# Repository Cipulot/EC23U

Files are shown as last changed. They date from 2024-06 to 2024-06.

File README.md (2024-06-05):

# EC23U

Open source numpad Electrostatic Capacitive PCB.

## Introduction

This project is a continuation of my development of open source EC boards.

The supported layout options are the following:

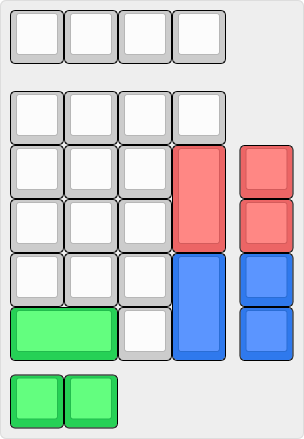
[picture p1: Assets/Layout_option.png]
Layout option


## Technical information

- Layout size: 23U layouts with alternative options
- Compatible switches: EC switches (Topre and NIZ)
- Microcontroller: STM32F401
- Connector: Original OEM JST connector
- Firmware compatibility: QMK (with VIA/VIAL support)
- Protection hardware (present on both the mainboard and both controller versions):
  - Fused
  - ESD protection
- Addressable RGB LED support
- Numlock LED support

## Renders and Prototypes

### Render

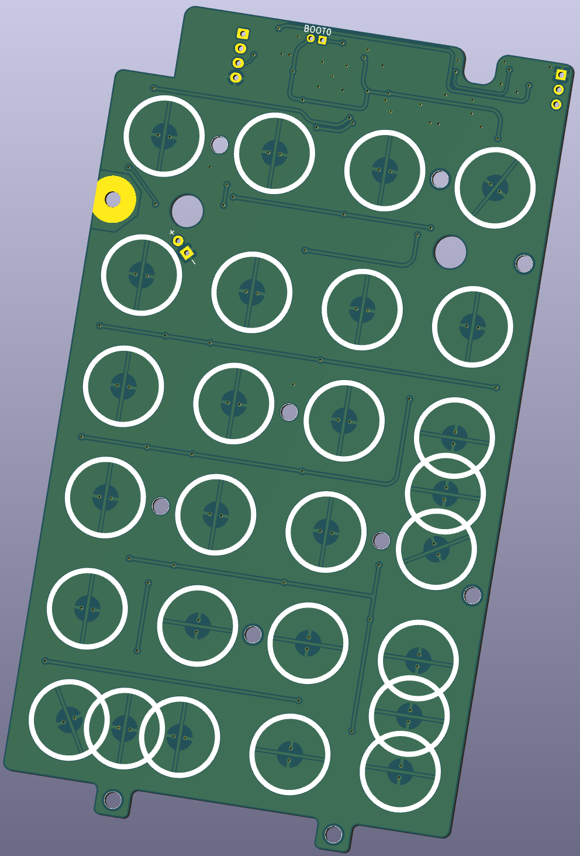
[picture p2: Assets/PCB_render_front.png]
PCB Front Render


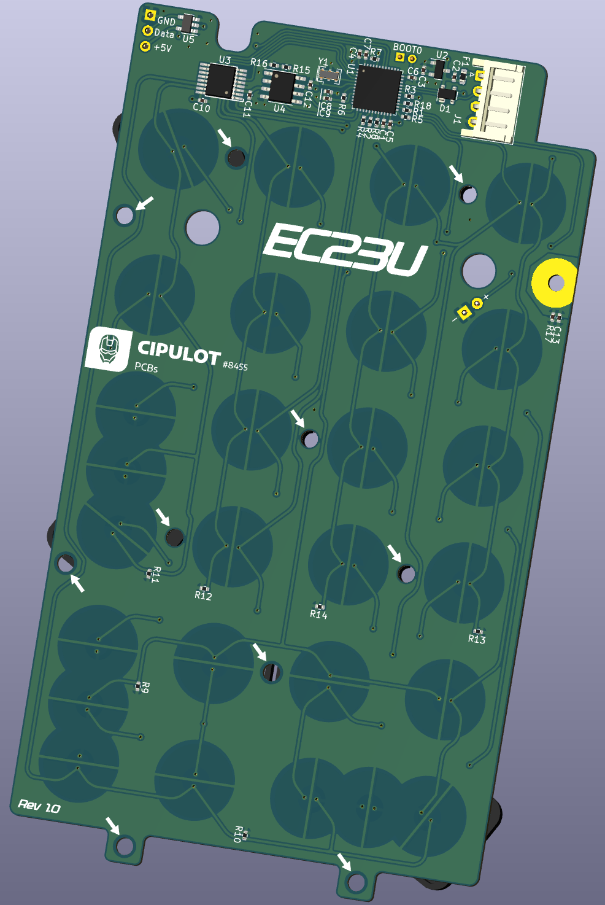
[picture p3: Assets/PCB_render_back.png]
PCB Back Render


### Prototypes

PCB Front

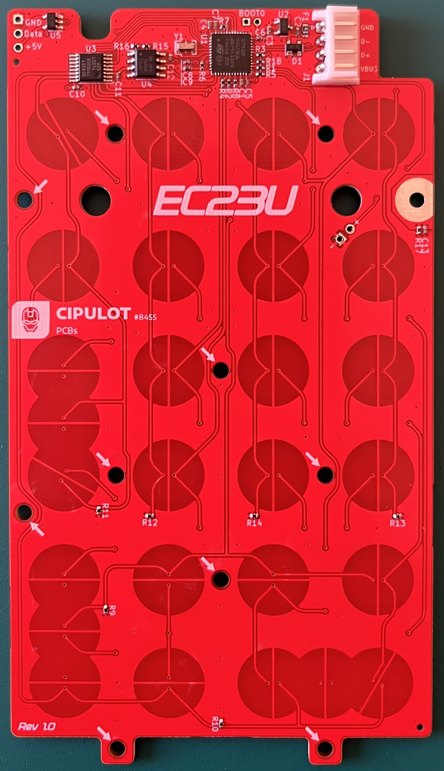
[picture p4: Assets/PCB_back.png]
PCB Back


**NOTE**: The silkscreen text near the JST connector has the `GND` and `VBUS` label swapped. This is wrong and have been fixed in the latest revision.

## Revisions and relative features

### Rev1.0

This revision implements all the main features of the mainboard ad controllers mentioned in the specifications.

#### RGB header

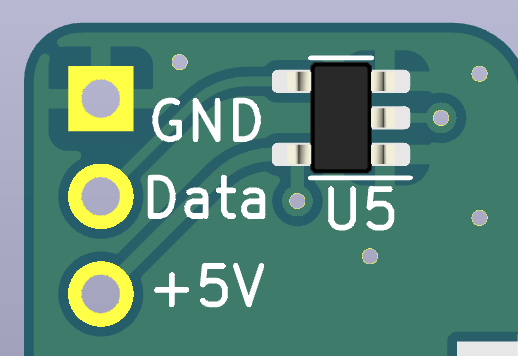
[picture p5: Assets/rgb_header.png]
RGB header


The mainboard features an RGB header for connecting +5V addressable RGB strips. THe properties of the lighting can be controlled through Vial or by assigning RGB control keycodes on the board itself.

#### NumLock Indicator

The mainboard features a NumLock indicator LED. The LED is controlled by the MCU and reacts based on the system state. The LED used is a 3.0mm THT LED. Polarity is signalled by the silkscreen. The indicator is optional.

#### DFU

To access the DFU mode of the mainboard you can perform one of the following actions:

- press the key to which the `QK_BOOT` keycode is assigned (if available)
- while plugging in the board short the `Boot0` pins on the mainboard

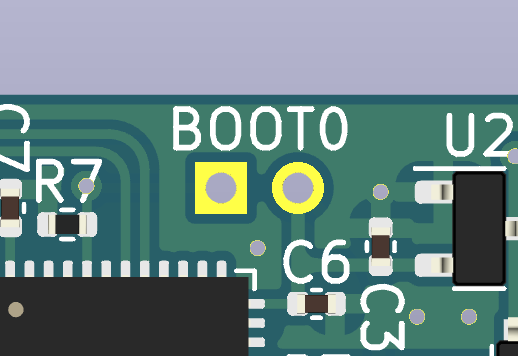
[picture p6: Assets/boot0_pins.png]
Boot0 pins


## PCB order procedure

### Production files

The production can be found in the [Production folder](/Production).

In there you'll find the main PCB files and the JIS and HHKB plates.

As usual the `*.zip` files are the gerber files, `BOM-*.csv` are the BOM (Bill Of Material) files and `POS-*.csv` are the POS/CPL (Footprint POSition/Component Placement List) files.

### Assembly options

Here follows the options to be used for assembly:

- Assembly Side: Bottom
- Confirm Parts Placement: `yes`

## Copyright notice

This project is not endorse nor sponsored in any way by Topre Corporation and PFU Limited. The HHKB Logo and Topre logo are trademarks of their respective owners.

## License

<br />This work is licensed under a <a rel="license" href="http://creativecommons.org/licenses/by-nc-sa/4.0/">Creative Commons Attribution-NonCommercial-ShareAlike 4.0 International License</a>.

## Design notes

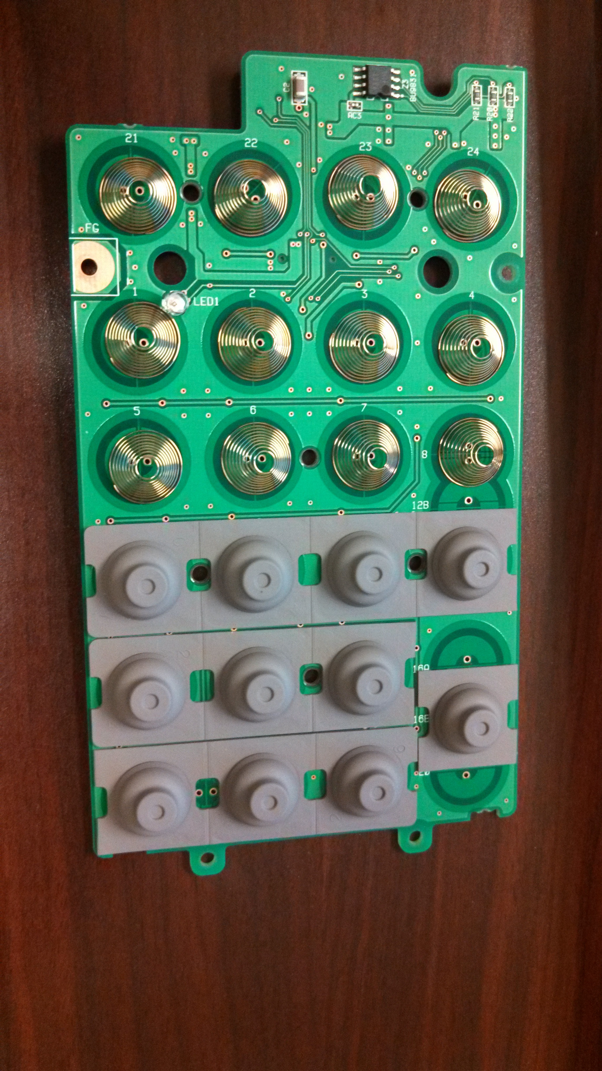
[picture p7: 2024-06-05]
Docs/23U Internals/11 - LMW1pFv.jpg

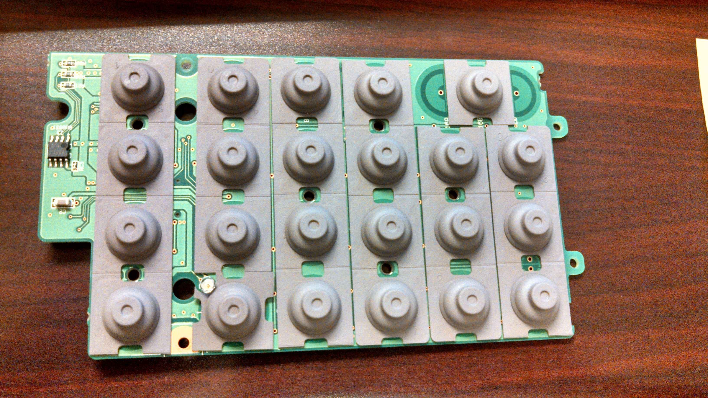
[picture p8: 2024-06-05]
Docs/23U Internals/3 - nLBDdjI.jpg

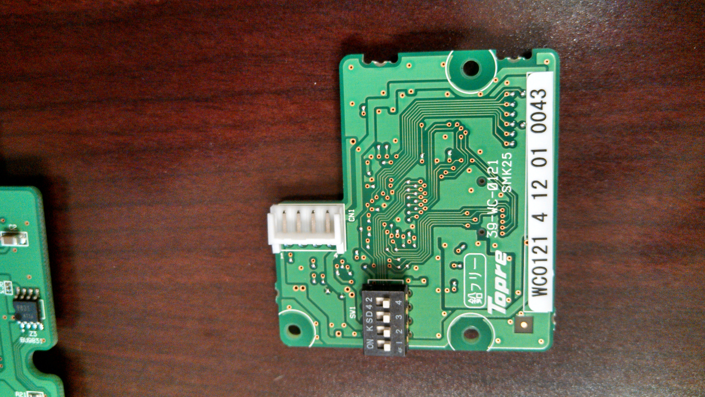
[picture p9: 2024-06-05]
Docs/23U Internals/10 - FUrgEg5.jpg

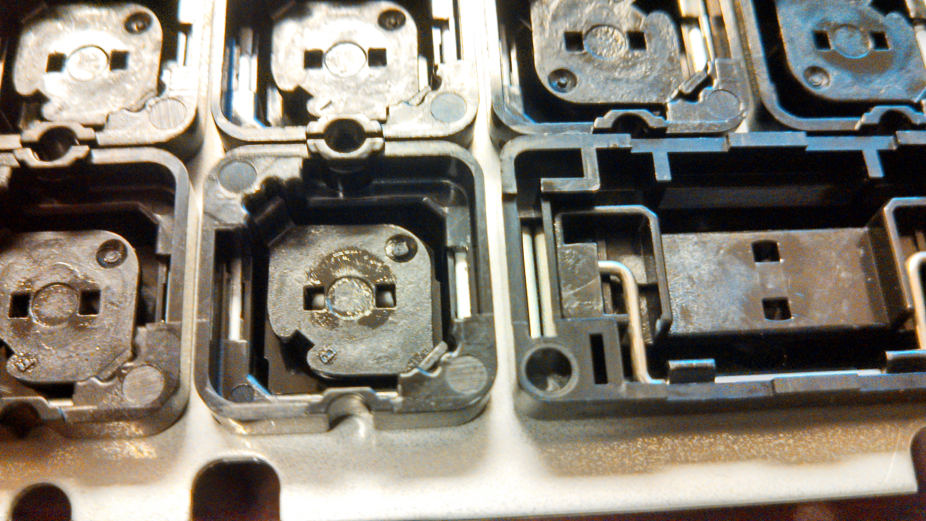
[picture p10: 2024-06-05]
Docs/23U Internals/1 - Ok48gKT.jpg

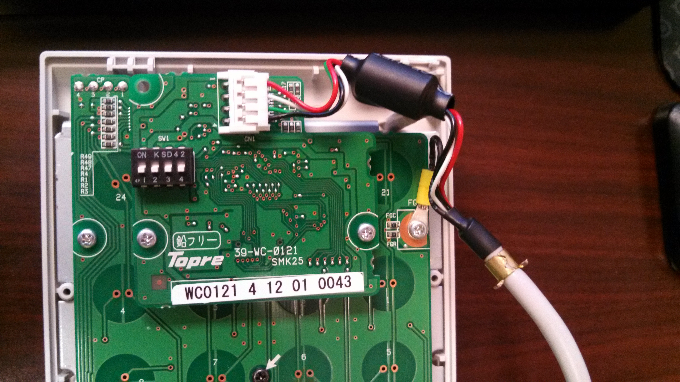
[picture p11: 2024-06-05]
Docs/23U Internals/4 - P8sS34b.jpg

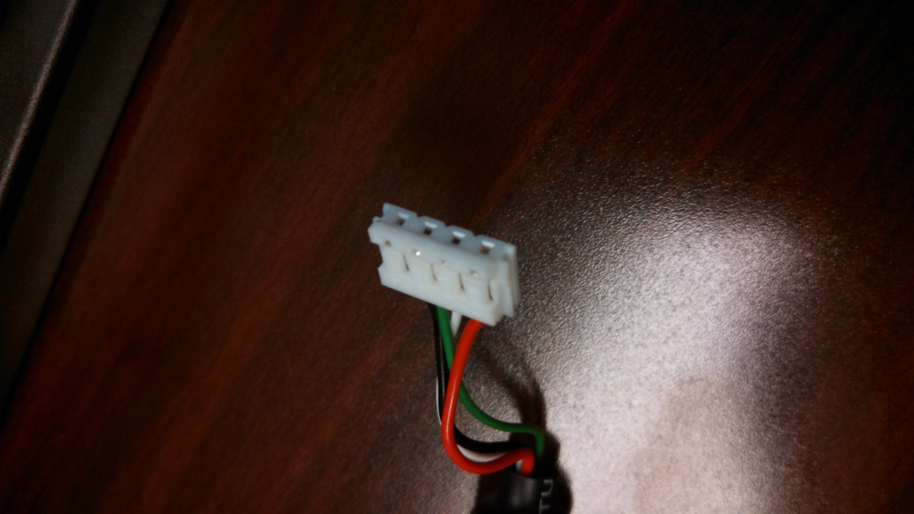
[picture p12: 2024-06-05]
Docs/23U Internals/7 - ExHz7Yd.jpg

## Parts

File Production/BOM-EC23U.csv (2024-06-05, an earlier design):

Comment | Designator | Footprint | LCSC
1k | R16 | R_0402_1005Metric | C11702
STM32F401CBUx | U1 | QFN-48-1EP_7x7mm_P0.5mm_EP5.6x5.6mm | C118825
OPA350 | U4 | SOIC-8_3.9x4.9mm_P1.27mm | C13388
220p | C11 | C_0402_1005Metric | C1530
4.7u | C1 | C_0402_1005Metric | C23733
100 | R1,R18,R2,R4,R5 | R_0402_1005Metric | C25076
330 | R17 | C_0402_1005Metric | C25104
100k | R10,R11,R12,R13,R14,R3,R9 | R_0402_1005Metric | C25741
10k | R6,R7,R8 | R_0402_1005Metric | C25744
47k | R15 | R_0402_1005Metric | C25792
JST | J1 | JST_EH_S4B-EH_1x04_P2.50mm_Horizontal | C265068
PRTR5V0U2X | D1 | SOT-143 | C2827688
100n | C10,C12,C13,C4,C5,C6,C7,C8 | C_0402_1005Metric | C307331
1u | C2,C3,C9 | C_0402_1005Metric | C52923
XC6206PxxxMR | U2 | SOT-23 | C5446
74HC4051 | U3 | TSSOP16 | C5645
500mA | F1 | Fuse_0603_1608Metric | C720073
SN74AHCT1G125 | U5 | SOT-23-5 | C7484
8 MHz | Y1 | Resonator_SMD_Murata_CSTxExxV-3Pin_3.0x1.1mm | C907975

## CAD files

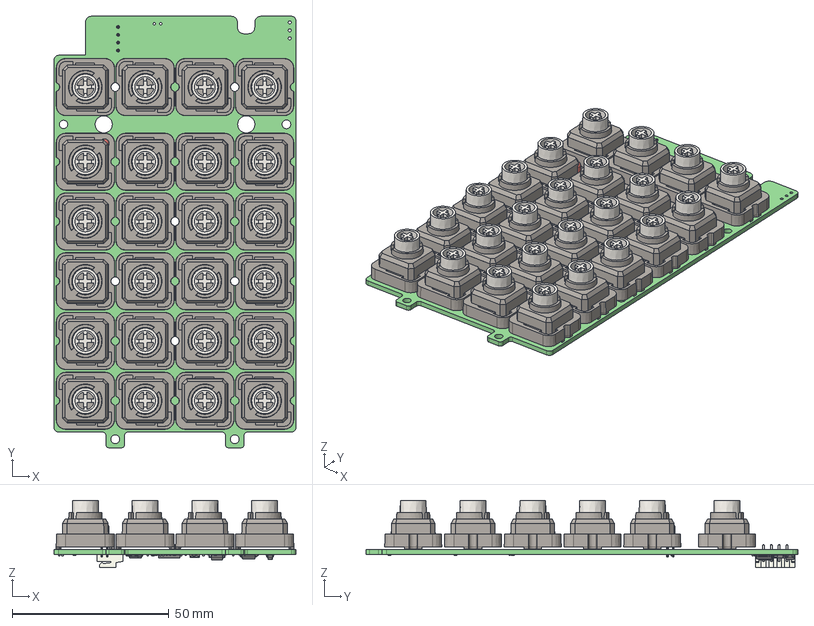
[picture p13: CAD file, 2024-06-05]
Assemblies_3D_Models/EC23U_Full_1U_Numpad.step
77.2 x 137.6 x 21.4 mm
EC23U PCB

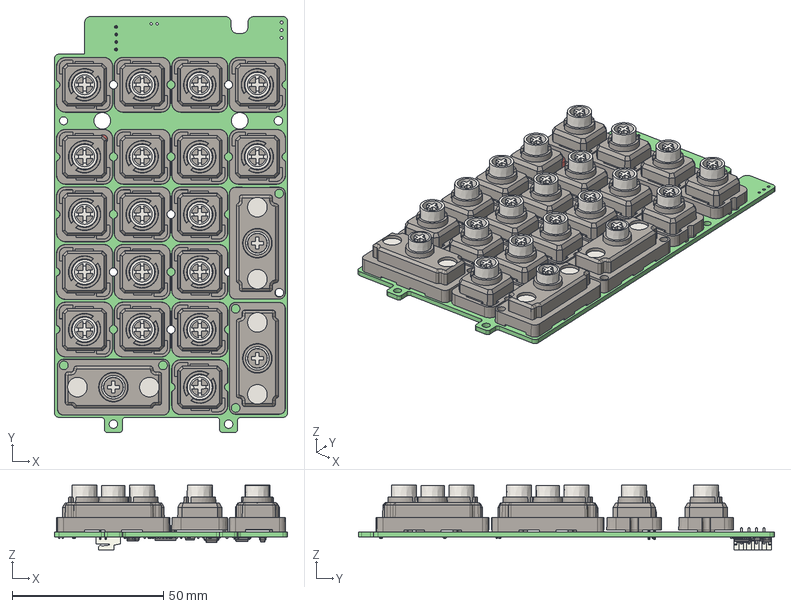
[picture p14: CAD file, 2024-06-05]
Assemblies_3D_Models/EC23U_Standard_Numpad.step
77.2 x 137.6 x 21.4 mm
EC23U PCB

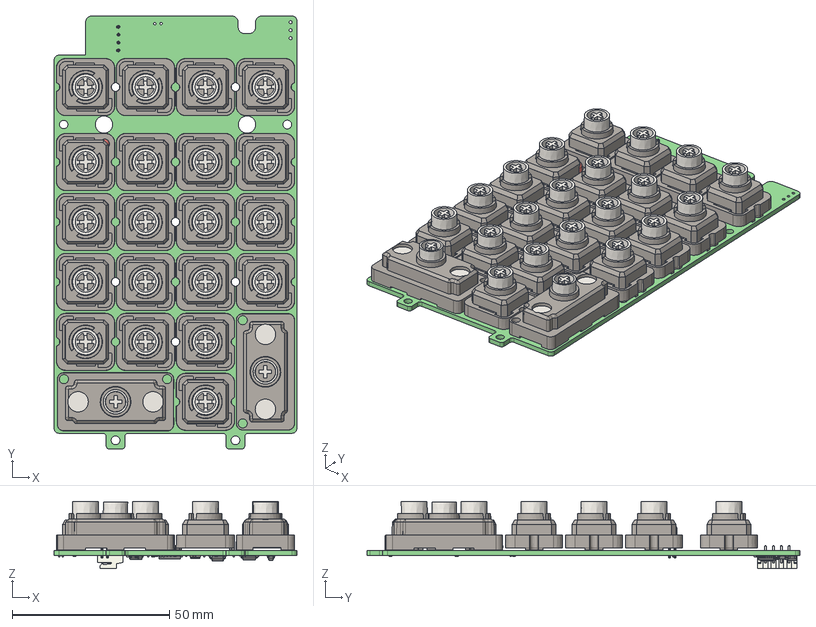
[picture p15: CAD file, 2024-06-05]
Assemblies_3D_Models/EC23U_Apple_Numpad.step
77.2 x 137.6 x 21.4 mm
EC23U PCB

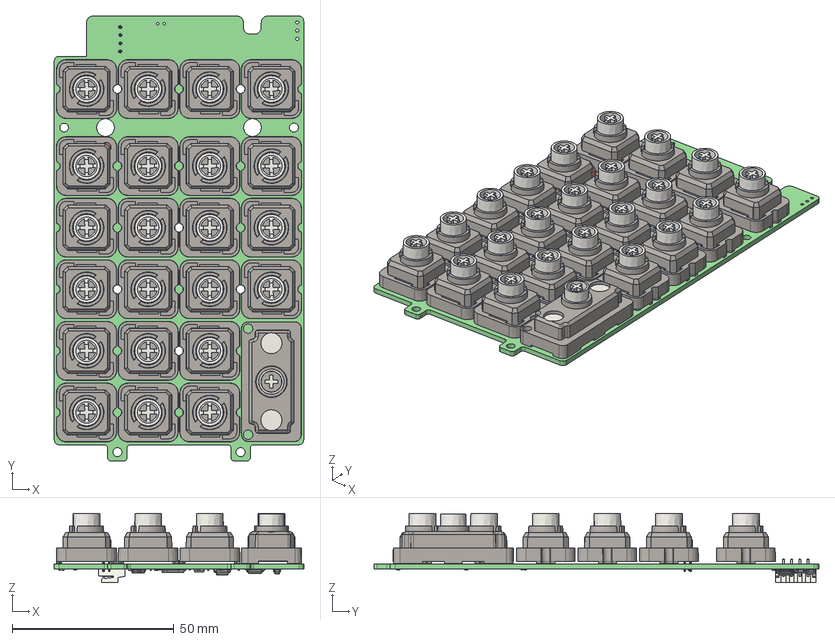
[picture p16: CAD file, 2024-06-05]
Assemblies_3D_Models/EC23U_Realforce_Numpad.step
77.2 x 137.6 x 21.4 mm
EC23U PCB

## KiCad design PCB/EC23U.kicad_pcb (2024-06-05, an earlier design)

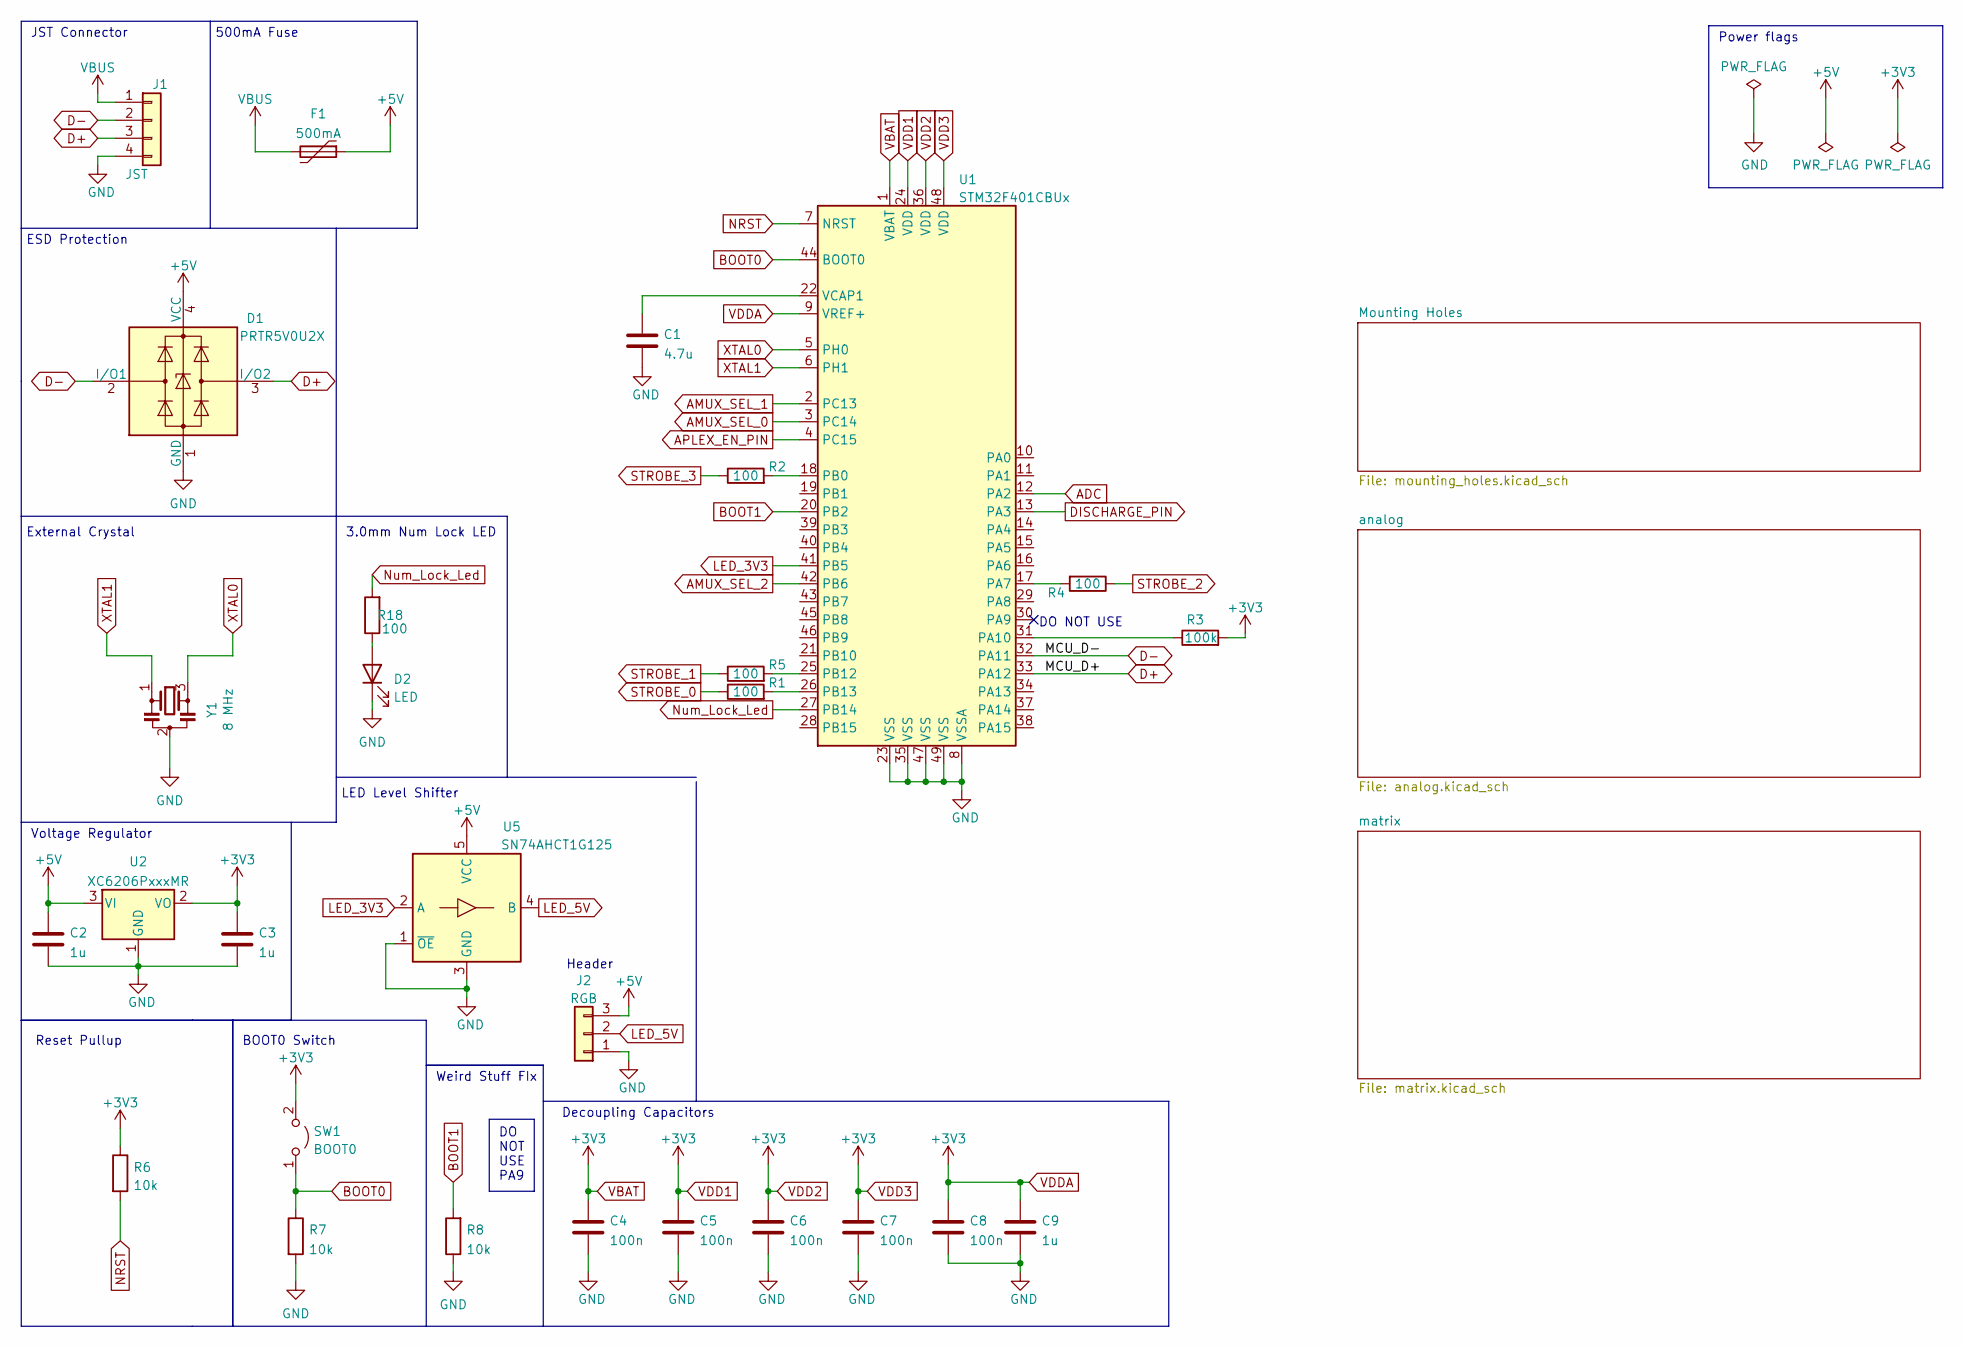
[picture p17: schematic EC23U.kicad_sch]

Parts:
C1: 4.7u; C_0402_1005Metric; LCSC C23733
C2, C3, C9: 1u; C_0402_1005Metric; LCSC C52923
C4, C5, C6, C7, C8: 100n; C_0402_1005Metric; LCSC C307331
D1: PRTR5V0U2X; SOT-143; LCSC C2827688
D2: LED; LED_D3.0mm
F1: 500mA; Fuse_0603_1608Metric; LCSC C720073
J1: JST; JST_EH_S4B-EH_1x04_P2.50mm_Horizontal; LCSC C265068
J2: RGB; PinSocket_1x03_P2.54mm_Vertical
R1, R2, R4, R5, R18: 100; R_0402_1005Metric; LCSC C25076
R3: 100k; R_0402_1005Metric; LCSC C25741
R6, R7, R8: 10k; R_0402_1005Metric; LCSC C25744
SW1: BOOT0; PinHeader_1x02_P2.00mm_Vertical
U1: STM32F401CBUx; QFN-48-1EP_7x7mm_P0.5mm_EP5.6x5.6mm; LCSC C118825
U2: XC6206PxxxMR; SOT-23; LCSC C5446
U5: SN74AHCT1G125; SOT-23-5; LCSC C7484
Y1: 8 MHz; Resonator_SMD_Murata_CSTxExxV-3Pin_3.0x1.1mm; LCSC C907975

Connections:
+5V: C2.1, D1.4 (VCC), F1.1, J2.3, U2.3 (VI), U5.5 (VCC)
ADC: U1.12 (PA2); also elsewhere on the board
AMUX_SEL_0: U1.3 (PC14); also elsewhere on the board
AMUX_SEL_1: U1.2 (PC13); also elsewhere on the board
AMUX_SEL_2: U1.42 (PB6); also elsewhere on the board
APLEX_EN_PIN: U1.4 (PC15); also elsewhere on the board
APLEX_OUT_PIN: U1.13 (PA3); also elsewhere on the board
BOOT0: R7.1, SW1.1 (A), U1.44 (BOOT0)
BOOT1: R8.2, U1.20 (PB2)
D+: D1.3 (I/O2), J1.3, U1.33 (PA12)
D-: D1.2 (I/O1), J1.2, U1.32 (PA11)
GND: C1.2, C2.2, C3.2, C4.2, C5.2, C6.2, C7.2, C8.2, C9.2, D1.1 (GND), D2.1 (K), J1.4, J2.1, R7.2, R8.1, U1.8 (VSSA), U1.23 (VSS), U1.35 (VSS), U1.47 (VSS), U1.49 (VSS), U2.1 (GND), U5.1 (~OE), U5.3 (GND), Y1.2; also elsewhere on the board
LED_3V3: U1.41 (PB5), U5.2 (A)
LED_5V: J2.2, U5.4 (B)
NRST: R6.2, U1.7 (NRST)
unnamed: D2.2 (A), R18.1
unnamed: R4.2, U1.17 (PA7)
unnamed: R3.1, U1.31 (PA10)
unnamed: R2.2, U1.18 (PB0)
unnamed: R5.2, U1.25 (PB12)
unnamed: R1.2, U1.26 (PB13)
unnamed: C1.1, U1.22 (VCAP1)
Num_Lock_Led: R18.2, U1.27 (PB14)
STROBE_0: R1.1; also elsewhere on the board
STROBE_1: R5.1; also elsewhere on the board
STROBE_2: R4.1; also elsewhere on the board
STROBE_3: R2.1; also elsewhere on the board
VBAT: C3.1, C4.1, C5.1, C6.1, C7.1, C8.1, C9.1, R3.2, R6.1, SW1.2 (B), U1.1 (VBAT), U1.9 (VREF+), U1.24 (VDD), U1.36 (VDD), U1.48 (VDD), U2.2 (VO); also elsewhere on the board
VBUS: F1.2, J1.1
XTAL0: U1.5 (PH0), Y1.3
XTAL1: U1.6 (PH1), Y1.1

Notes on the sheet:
Voltage Regulator
Weird Stuff FIx
3.0mm Num Lock LED
Decoupling Capacitors
BOOT0 Switch
DO NOT USE
DO NOT USE PA9
LED Level Shifter
External Crystal
500mA Fuse
Header
JST Connector
ESD Protection
Reset Pullup
Power flags

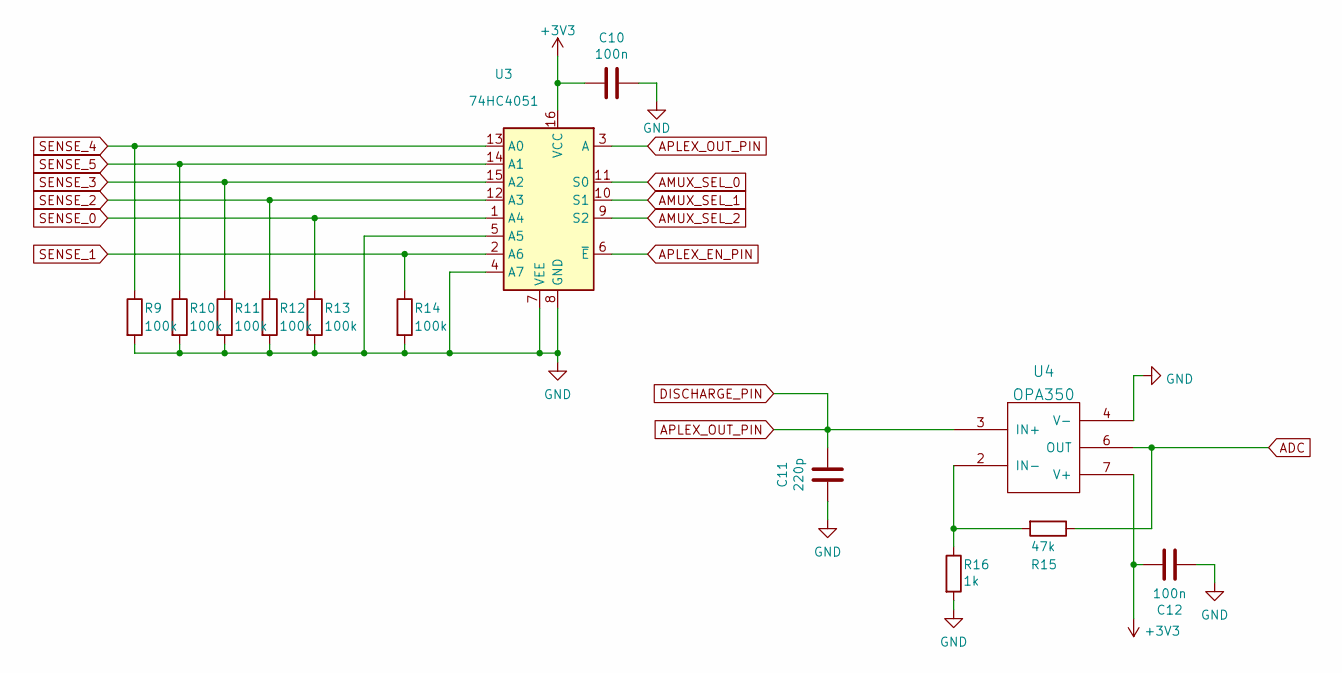
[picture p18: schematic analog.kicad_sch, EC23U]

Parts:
C10, C12: 100n; C_0402_1005Metric; LCSC C307331
C11: 220p; C_0402_1005Metric; LCSC C1530
R9, R10, R11, R12, R13, R14: 100k; R_0402_1005Metric; LCSC C25741
R15: 47k; R_0402_1005Metric; LCSC C25792
R16: 1k; R_0402_1005Metric; LCSC C11702
U3: 74HC4051; TSSOP16; LCSC C5645
U4: OPA350; SOIC-8_3.9x4.9mm_P1.27mm; LCSC C13388

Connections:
ADC: R15.1, U4.6 (OUT); also elsewhere on the board
AMUX_SEL_0: U3.11 (S0); also elsewhere on the board
AMUX_SEL_1: U3.10 (S1); also elsewhere on the board
AMUX_SEL_2: U3.9 (S2); also elsewhere on the board
APLEX_EN_PIN: U3.6 (~E); also elsewhere on the board
APLEX_OUT_PIN: C11.1, U3.3 (A), U4.3 (IN+); also elsewhere on the board
GND: C10.1, C11.2, C12.1, R9.2, R10.2, R11.2, R12.2, R13.2, R14.2, R16.2, U3.4 (A7), U3.5 (A5), U3.7 (VEE), U3.8 (GND), U4.4 (V-); also elsewhere on the board
unnamed: R15.2, R16.1, U4.2 (IN-)
SENSE_0: R13.1, U3.1 (A4); also elsewhere on the board
SENSE_1: R14.1, U3.2 (A6); also elsewhere on the board
SENSE_2: R12.1, U3.12 (A3); also elsewhere on the board
SENSE_3: R11.1, U3.15 (A2); also elsewhere on the board
SENSE_4: R9.1, U3.13 (A0); also elsewhere on the board
SENSE_5: R10.1, U3.14 (A1); also elsewhere on the board
VBAT: C10.2, C12.2, U3.16 (VCC), U4.7 (V+); also elsewhere on the board

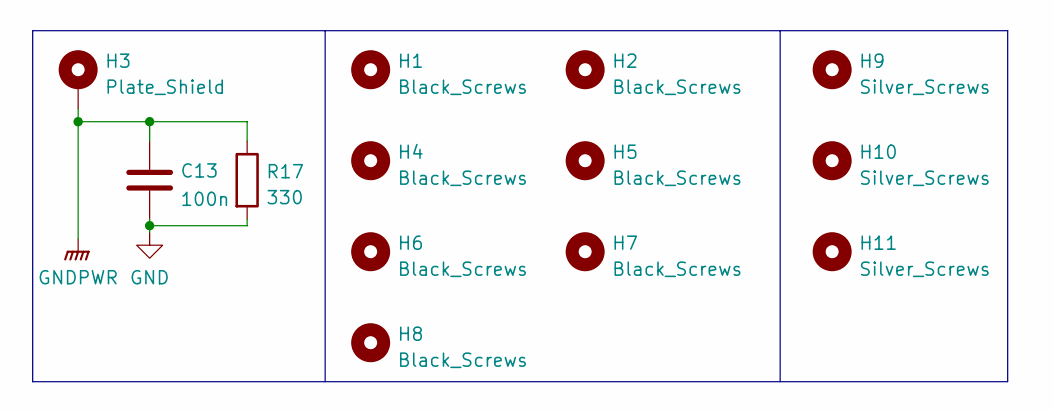
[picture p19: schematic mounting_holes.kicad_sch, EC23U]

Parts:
C13: 100n; C_0402_1005Metric; LCSC C307331
H1, H2, H4, H5, H6, H7, H8: Black_Screws; HOLE_M2_RF
H3: Plate_Shield; MountingHole_2.2mm_M2_Pad
H9, H10, H11: Silver_Screws; HOLE_M2_RF
R17: 330; C_0402_1005Metric; LCSC C25104

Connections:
GND: C13.2, R17.2; also elsewhere on the board
GNDPWR: C13.1, H3.1, R17.1

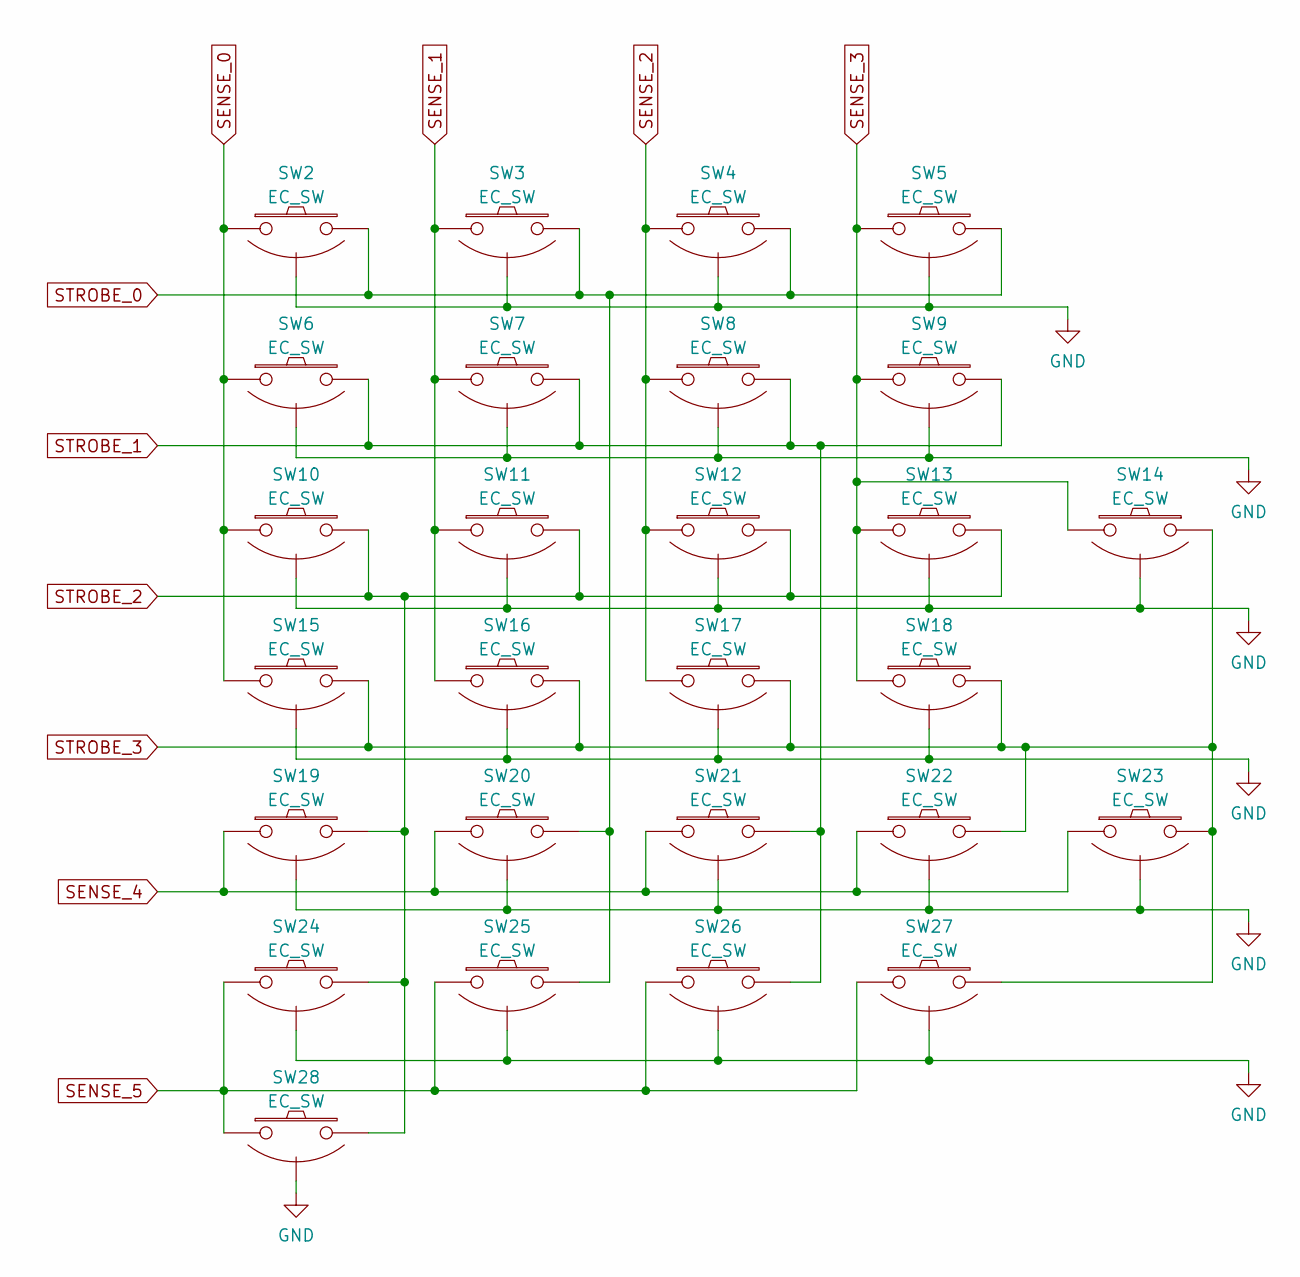
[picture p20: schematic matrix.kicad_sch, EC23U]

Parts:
SW2, SW3, SW4, SW5, SW6, SW7, SW8, SW9, SW10, SW11, SW12, SW13, SW15, SW16, SW17, SW18, SW19, SW20, SW21, SW22, SW24, SW25, SW26, SW27: EC_SW; ecs_pad_1U_no_ring
SW14, SW23, SW28: EC_SW; ecs_pad_2U_no_ring

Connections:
GND: SW2.3 (SG), SW3.3 (SG), SW4.3 (SG), SW5.3 (SG), SW6.3 (SG), SW7.3 (SG), SW8.3 (SG), SW9.3 (SG), SW10.3 (SG), SW11.3 (SG), SW12.3 (SG), SW13.3 (SG), SW14.3 (SG), SW15.3 (SG), SW16.3 (SG), SW17.3 (SG), SW18.3 (SG), SW19.3 (SG), SW20.3 (SG), SW21.3 (SG), SW22.3 (SG), SW23.3 (SG), SW24.3 (SG), SW25.3 (SG), SW26.3 (SG), SW27.3 (SG), SW28.3 (SG); also elsewhere on the board
SENSE_0: SW2.1, SW6.1, SW10.1, SW15.1; also elsewhere on the board
SENSE_1: SW3.1, SW7.1, SW11.1, SW16.1; also elsewhere on the board
SENSE_2: SW4.1, SW8.1, SW12.1, SW17.1; also elsewhere on the board
SENSE_3: SW5.1, SW9.1, SW13.1, SW14.2, SW18.1; also elsewhere on the board
SENSE_4: SW19.1, SW20.1, SW21.1, SW22.1, SW23.1; also elsewhere on the board
SENSE_5: SW24.1, SW25.1, SW26.1, SW27.1, SW28.1; also elsewhere on the board
STROBE_0: SW2.2, SW3.2, SW4.2, SW5.2, SW20.2, SW25.2; also elsewhere on the board
STROBE_1: SW6.2, SW7.2, SW8.2, SW9.2, SW21.2, SW26.2; also elsewhere on the board
STROBE_2: SW10.2, SW11.2, SW12.2, SW13.2, SW19.2, SW24.2, SW28.2; also elsewhere on the board
STROBE_3: SW14.1, SW15.2, SW16.2, SW17.2, SW18.2, SW22.2, SW23.2, SW27.2; also elsewhere on the board

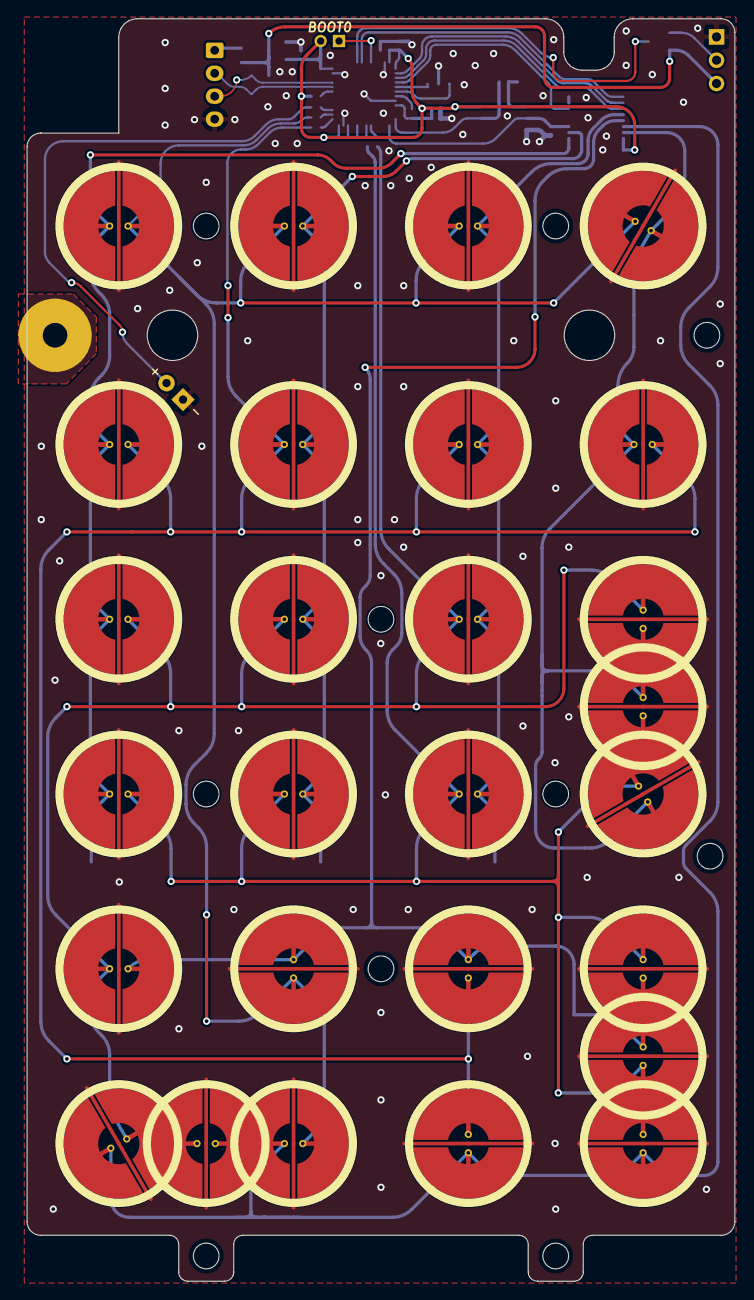
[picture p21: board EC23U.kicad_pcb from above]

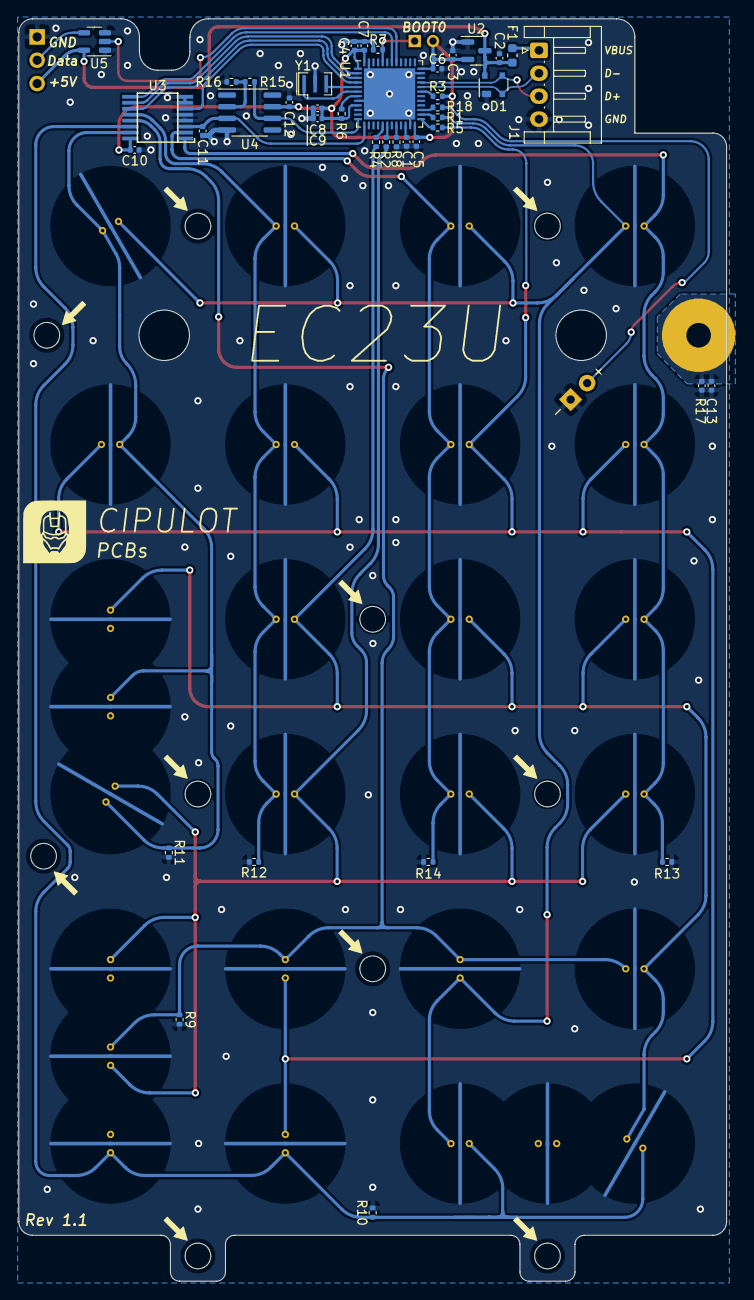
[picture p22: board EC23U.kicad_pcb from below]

Board: 2 copper layers, 77.1 x 137.6 mm, 81 parts (40 on the bottom side), 39 nets.

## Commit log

2023-02-23 Kicad 7 update and change of resistor value
    [BOM-EC23U.csv, EC23U.kicad_pcb, EC23U.kicad_sch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]
2023-07-15 Updated to `Rev 1.1`
    Updated the title block in schematics to reflect company name and updated EC pads to latest model.
    This update isn't critical, hence the lack of proper `Rev` update in README.
    [EC23U.kicad_pcb, EC23U.kicad_sch, analog.kicad_sch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]
2023-08-19 Addition of new FW
    New Sideload firmware release that enables new features as:
    - Rapid Trigger (still WIP with bugs)
    - Calibration
    Compatible with previous revisions PCBs.
2023-11-17 Updated sheets
    [EC23U.kicad_pcb, EC23U.kicad_sch, analog.kicad_sch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]
2024-03-03 Update
    Updated the License for the project and relative details.
    [EC23U.kicad_pcb, EC23U.kicad_sch, analog.kicad_sch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]
2024-06-05 EC23U Cleanup
    [BOM-EC23U.csv, EC23U.kicad_pcb, EC23U.kicad_sch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]

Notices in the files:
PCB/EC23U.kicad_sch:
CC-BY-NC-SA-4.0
